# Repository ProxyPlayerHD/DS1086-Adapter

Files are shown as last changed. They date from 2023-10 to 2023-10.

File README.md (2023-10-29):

# DS1086-Adapter
SMT to DIP-8 Adapter for the DS1086 Programmable Clock Generator, Including an Arduino Sketch to program the chip

Clock Compare

This repo has the full Kicad Project including gerbers, and a PDF of the schematic. Of course it also includes the Arduino Sketch which contains the code nessesary to program the chip over a CLI like interface via serial.

It's fairly simple:

first make sure that whatever terminal you use for the Arduino uses LF characters for new lines (no CR or CR+LF)  
then connect the 4 pins of the Adapter (5V, GND, SDA, SCL) to the appropriate pins on whatever 5V arduino board you're using  
finally power the thing up and wait for the small splash screen  
after that you simply enter commands like with any other CLI, the supported commands are as follows:  

* help - displays a list of all commands and what they do
* get - displays the current clock speed of the DS1086
* set <freq. in kHz> - sets the clock speed of the DS1086 to the specified value
* write - saves the current clock speed to the EEPROM

note that the DAC Register always reads the same value regardless of the contents of the Register, so the read out can be off by up to 5MHz. if you want to be sure the speed is correct just use an Oscilloscope.

On a different note the headers for the programming interface are split because of space constraints as i wanted the whole thing to fit into the footprint of an actual DIP-8 Oscillator can.
If vertial space is a premium, the programming headers can be left unpopulated in which case you just put some wires into the holes and hold them with your fingers while programming it.

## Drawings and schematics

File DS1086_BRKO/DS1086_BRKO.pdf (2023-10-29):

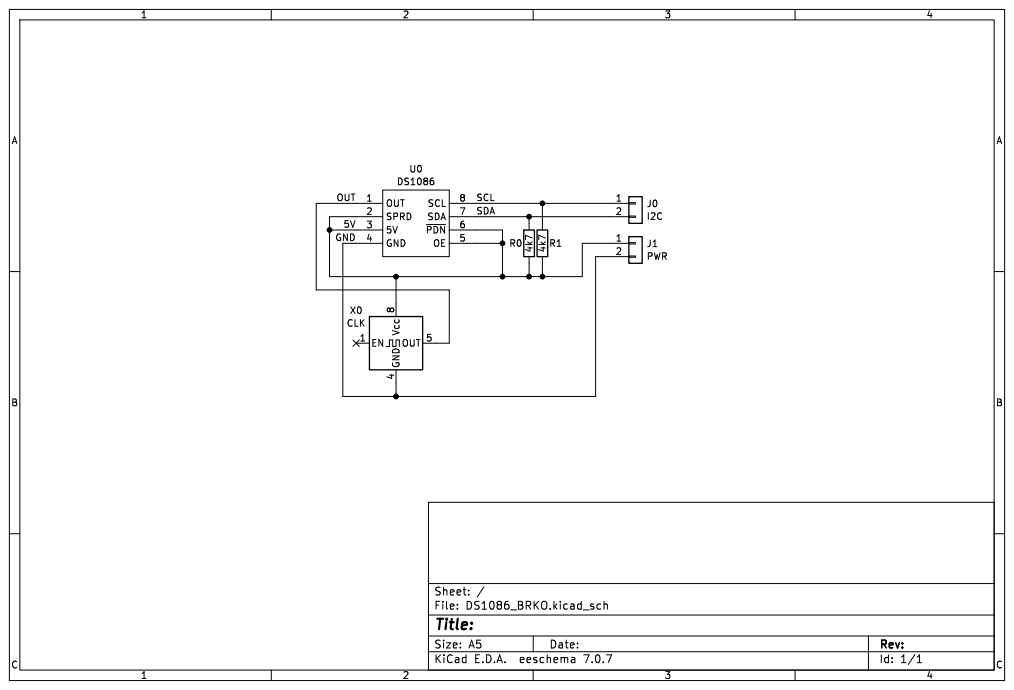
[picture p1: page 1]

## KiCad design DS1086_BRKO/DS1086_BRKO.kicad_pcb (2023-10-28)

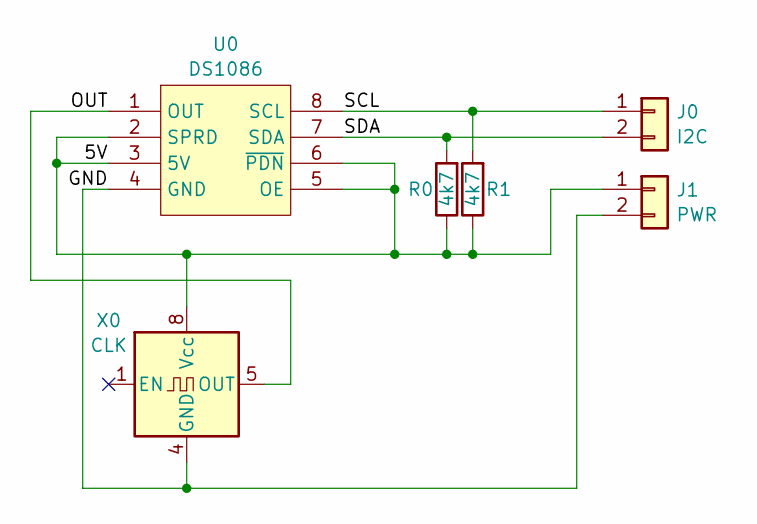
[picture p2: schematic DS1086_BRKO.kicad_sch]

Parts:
J0: I2C; PinHeader_1x02_P2.54mm_Vertical
J1: PWR; PinHeader_1x02_P2.54mm_Vertical
R0, R1: 4k7; R_Axial_DIN0204_L3.6mm_D1.6mm_P7.62mm_Horizontal
U0: DS1086; MSOP-8_3x3mm_P0.65mm
X0: CLK; Oscillator_DIP-8

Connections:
/5V: J1.1, R0.1, R1.1, U0.2 (SPRD), U0.3 (5V), U0.5 (OE), U0.6 (~PDN), X0.8 (Vcc)
/GND: J1.2, U0.4 (GND), X0.4 (GND)
/OUT: U0.1 (OUT), X0.5 (OUT)
/SCL: J0.1, R1.2, U0.8 (SCL)
/SDA: J0.2, R0.2, U0.7 (SDA)

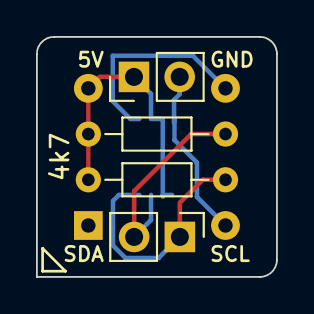
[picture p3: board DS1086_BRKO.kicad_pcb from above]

Board: 2 copper layers, 13.3 x 13.3 mm, 6 parts (1 on the bottom side), 5 nets.

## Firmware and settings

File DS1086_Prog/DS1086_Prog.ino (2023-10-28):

#include <Wire.h>



enum{
	REG_PRSC = 0x02,
	REG_DACH = 0x08,
	REG_DACL = 0x09,
	REG_OFFS = 0x0E,
	REG_ADDR = 0x0D,
	REG_RNGE = 0x37,
	REG_WREE = 0x3F
};

uint8_t readRegister(uint8_t adr){
	uint8_t tmp;
	Wire.beginTransmission(0x58);	// Start Transfer
	Wire.write(adr);				// Write the Register's Address
	Wire.endTransmission(false);	// Do not release the line
	Wire.requestFrom(0x58, 1);		// Request the value in the Register
	tmp = Wire.read();				// And Return the read Byte
	delay(10);
	// Serial.print("Read from Register: 0x");
	// Serial.print(adr, HEX);
	// Serial.print(" a Value of: 0x");
	// Serial.println(tmp, HEX);
	return tmp;
}

void writeRegister(uint8_t adr, uint8_t val){
	Wire.beginTransmission(0x58);	// Start Transfer  
	Wire.write(adr);				// Write the Register's Address
	Wire.write(val);				// Write Value to the specified Register
	Wire.endTransmission();			// And end the Transfer
	delay(10);
	// Serial.print("Write to Register: 0x");
	// Serial.print(adr, HEX);
	// Serial.print(" a Value of: 0x");
	// Serial.println(val, HEX);
}

#define readPrescaler()				(readRegister(REG_PRSC) & 0x0F)
#define readDither()				(!!(readRegister(REG_PRSC) & 0x10))
#define readDAC()					((((uint16_t)readRegister(REG_DACL) >> 6U) & 0x0003) | (((uint16_t)readRegister(REG_DACH) << 2U) & 0x03FC))
#define readOffset()				(readRegister(REG_OFFS) & 0x1F)
#define readAddress()				(readRegister(REG_ADDR) & 0x07)
#define readWC()					(!!(readRegister(REG_ADDR) & 0x08))
#define readRange()					(readRegister(REG_RNGE) & 0x1F)

#define writePrescaler(v, d)		writeRegister(REG_PRSC, (v & 0x0F) | (d ? 0x10 : 0x00))
#define writeDACH(v)				writeRegister(REG_DACH, (v >> 2U) & 0x00FF)
#define writeDACL(v)				writeRegister(REG_DACL, (v << 6U) & 0x00C0)
#define writeOffset(v)				writeRegister(REG_OFFS, v & 0x1F)
#define writeAddress(v)				writeRegister(REG_ADDR, (readRegister(REG_ADDR) & 0x08) | (v & 0x07))
#define writeWC(v)					writeRegister(REG_ADDR, (readRegister(REG_ADDR) & 0x07) | (v ? 0x08 : 0x00))
#define writeRange(v)				writeRegister(REG_RNGE, v & 0x1F)



typedef struct{
	const char *name;
	void (*func)(uint16_t);
} cmd_t;

uint16_t readLine();
bool executeLine(uint16_t len);
void cmdHelp(uint16_t idx);
void cmdGet(uint16_t idx);
void cmdSet(uint16_t idx);
void cmdWrite(uint16_t idx);

#define BUF_SIZE					(256U)
char inbuf[BUF_SIZE];				// Input Line Buffer

char debugStr[200];

#define CMD_COUNT					(4U)
const cmd_t commands[] = {
	{.name = "help", .func = cmdHelp},
	{.name = "get", .func = cmdGet},
	{.name = "set", .func = cmdSet},
	{.name = "write", .func = cmdWrite}
};


void setup(){
	Wire.begin(); 
	Serial.begin(9600);
	delay(1000);
	Serial.println("DS1086 Programmer v1\nType \"help\" for a list of commands");
	
}

void loop(){
	
	Serial.print(">");
	
	
	// Wait for a Line of Text from Serial
	uint16_t bufLen = 0;
	while(!bufLen){
		bufLen = readLine();
	}
	
	
	// Check if it is a valid command
	// If so call the correct function to execute that command
	if (!executeLine(bufLen)){
		// If not display an error and return to start
		Serial.println("Command not found");
	}
	
	
}




// Reads a line from Serial,
// Returns a non-zero value if it was successful
uint16_t readLine(){
	uint16_t i = 0;
	char tmp;
	while(1){
		while(!Serial.available()){};	// Wait for a character
		tmp = Serial.read();			// Then read it
		Serial.print(tmp);				// Also echo it back to the Terminal
		
		if (tmp == '\n') break;			// If it's a newline, the string is done
		if (tmp == '\b'){				// If it's a backspace, move the pointer back one character
			i--;
		}else{
			inbuf[i++] = tmp;			// If it wasn't a backspace, add the character to the buffer and increment the pointer
		}
		if (i >= BUF_SIZE) return 0;	// If the amount of characters exceeds the buffer size, return early
	}
	inbuf[i] = 0;
	return i;
}

// Grabs the first word (ie all character up to a whitespace character) in the inbuf,
// Converts it to all lowercase,
// And checks if it matches any internal commands,
// If it does it passes the rest of the inbuf to the function specific for that command,
// Returns false if no matching command was found
bool executeLine(uint16_t len){
	uint16_t i = 0;
	while(1){								// Split off the first word in the buffer
		if (inbuf[i] == ' ') break;			// If a whitespace character has been reached, exit the loop
		if (inbuf[i] == 0) break;			// Alternatively If a NULL terminator has been reached, exit the loop as well
		if (i >= BUF_SIZE) return false;	// Also check if the end of the buffer has been reached in case the NULL terminator is gone for some reason
		inbuf[i] = tolower(inbuf[i]);		// If nothing have been reached, convert the character to lowercase
		i++;								// And then go to the next one
	}
	if (inbuf[i]){
		inbuf[i++] = 0;						// If the end has been found and it's not NULL terminated there, add a NULL terminator and advance the pointer to the next part of the string
	}
	
	
	// Now iterate through all commands and check if any match
	uint8_t cmd = 0;
	for (cmd = 0; cmd < CMD_COUNT; cmd++){
		//snprintf(debugStr, 199, "[debug] comparing \"%s\" and \"%s\"", commands[cmd].name, inbuf);
		//Serial.println(debugStr);
		if (!strcmp(commands[cmd].name, inbuf)){
			commands[cmd].func(i);
			return true;
		}
	}
	
	// If this point is reached, no command was found and executed
	return false;
}


void cmdHelp(uint16_t idx){
	Serial.println("Commands:");
	Serial.println("  \"help\"                   - Displays this message");
	Serial.println("  \"get\"                    - Read and display the current clock Speed");
	Serial.println("  \"set <frequency in kHz>\" - Set the clock speed to the specified frequency (or the closest approximation)");
	Serial.println("  \"write\"                  - Saves the current clock speed to the DS1086's EEPROM\n");
}

void cmdGet(uint16_t idx){
	// First set the WC bit to prevent automatic EE writes (even though this fuction does no writes)
	writeWC(true);
	
	uint16_t exponent = readPrescaler();						// Get the Exponent (values between 0-8)
	uint16_t offsetIndex = (readOffset() - readRange()) + 6;	// Get the offset index (values between 0-12)
	uint16_t DAC = readDAC();									// Get the DAC (values between 0-1023)
	
	if (exponent > 8) exponent = 8;
	
	uint32_t minOffsetFreq = (61440UL + (offsetIndex * 5120UL));
	
	float frequency = (((float)minOffsetFreq + (float)DAC * 10.0f) / (float)(1UL << exponent)) / 1000.0f;
	
	
	snprintf(debugStr, 199, "[debug]\n  Offset: %d (Index: %u)\n  Exponent: %u\n  DAC Value: %u (%04X)\n  Min Offset Frequency: %lu", readOffset(), offsetIndex, exponent, DAC, DAC, minOffsetFreq);
	Serial.println(debugStr);
	
	
	Serial.print("Current Frequency is: ");
	Serial.print(frequency, 2);
	Serial.println("MHz");
	
}

void cmdSet(uint16_t idx){
	if (inbuf[idx] == 0){		// Check if the String is empty
		Serial.println("No frequency given");
		return;					// If it is print an error and return
	}
	
	// First set the WC bit to prevent automatic EE writes
	writeWC(true);
	
	// Then get the specified target frequency
	uint32_t targetFreq = atol(&inbuf[idx]);
	
	// Check if it's within the bounds of the chip's capabilities (plus some buffer space)
	if ((targetFreq < 300UL) || (targetFreq >= 133000UL)){
		Serial.println("Target frequency out of range (300kHz - 133000kHz)");
		return;					// If it isn't, print an error and return
	}
	
	// Calculate the Prescaler value
	uint8_t exponent = 0;
	for (; exponent < 10; exponent++){
		// Check exponents until one is found that gets the target frequency into the 66-133MHz range
		if (((1U << exponent) * targetFreq) >= 66000UL) break;
	}
	
	if (exponent > 8){		// Return early if the exponent is out of range
		Serial.print("[debug] Exponent out of range");
		return;
	}
	
	// Next Calculate the Offset
	uint8_t offsetIndex = 0;
	uint32_t masterFreq = (1UL << exponent) * targetFreq;
	uint32_t minOffsetFreq;
	for (; offsetIndex < 13; offsetIndex++){
		minOffsetFreq = (61440UL + (offsetIndex * 5120UL));
		//snprintf(debugStr, 199, "[debug] checking if %lu is within range of %lu and %lu", masterFreq, minOffsetFreq, (minOffsetFreq + 10230UL));
		//Serial.println(debugStr);
		
		// if the required master frequency is within range of the current offset, exit the loop
		if ((masterFreq <= (minOffsetFreq + 10230UL)) && (masterFreq >= minOffsetFreq)) break;
	}
	if (offsetIndex > 12){	// Return early if the offset is out of range
		Serial.print("[debug] Offset Index out of range");
		return;
	}
	
	// Now check if the master frequency is closer to the current or next offset
	// To do this simply subtract the master frequency by the center frequency of the current offset and the next offset and see which delta is smaller
	// Also check if offsetIndex isn't 12 (ie OS+6) in which case it cannot be incremented anymore
	if (((masterFreq - (minOffsetFreq + 5115UL) > (masterFreq - (minOffsetFreq + 5115UL + 5120UL)))) && (offsetIndex != 12)){
		offsetIndex++;
	}
	
	uint8_t defaultRange = readRange();
	int8_t offset = (defaultRange - 6) + offsetIndex;
	
	uint16_t DAC = (masterFreq - (61440UL + (offsetIndex * 5120UL))) / 10;
	
	snprintf(debugStr, 199, "[debug]\n  Offset: %d (Index: %u)\n  Exponent: %u\n  DAC Value: %u (%04X)", offset, offsetIndex, exponent & 0x0F, DAC, DAC);
	Serial.println(debugStr);
	
	writePrescaler(exponent, true);		// Prescaler (and enable 4% Dither)
	writeOffset(offset);				// Offset
	writeDACH(DAC);
	writeDACL(DAC);						// DAC
	
	Serial.println("Frequency Successfully changed");
}

void cmdWrite(uint16_t idx){
	Wire.beginTransmission(0x58);
	Wire.write(REG_WREE);
	Wire.endTransmission();
}
